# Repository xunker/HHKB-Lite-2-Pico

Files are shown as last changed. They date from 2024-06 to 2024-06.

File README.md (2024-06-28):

**IMPORTANT**: Current design (June 2024) is *NOT* completely functional. Please
see [TODO.md](TODO.md) for more info.

# Pi Pico SMD controller relacement for HHKB Lite 2

Based on the [Teensy 2.0 controller by
thirteen37](https://github.com/thirteen37/HHKB-Lite-2-Teensy).

This is a QMK-compatible replacement controller for the [HHKB Lite
2](https://deskthority.net/wiki/HHKB_Lite), identified by model numbers
PD-KB200W/U or PD-KB200B/U.

This Lite version of the HHKB is a membrane keyboard and not exactly popular
compared to more expensive Professional versions that use Topre switches. But
the wiring is simple and is a good first project for modding commercial
keyboards.

This replacement uses a [Raspberry Pi Pico or Pico
W](https://www.raspberrypi.com/products/raspberry-pi-pico/), which is cheap, has
plenty of pins, and is supported by works well with the [QMK
firmware](https://github.com/qmk/qmk_firmware/blob/master/docs/platformdev_rp2040.md).
Note, this board uses the Pico as an SMD component (for space considerations)
and needs a Pico that *does not* have headers pre-soldered.

If you don't mind losing the built-in USB ports, then only 4 parts are required:
this PCB, two FFC connectors, and a Pi Pico. Optionally, you can add the
necessary components to integrate a USB 2.0 hub and keep using the built in USB
ports -- with the added benefit that they are now USB 2.0!

## Steps

1. Acquire/fabricate the PCB.
2. Get the parts
3. Disassemble the keyboard.
4. Solder the components on to the board. Take care to leave enough room for the
   USB cable.
5. Reconnect the flex cables and insulate the backplate.
6. Get the USB cable you will be using and insert it through the keyboard
   connector hole and plug it in to the Pi Pico.
7. Flash your firmware and test your keyboard.
8. Reassemble the shell.

### PCB fabrication

The fabrication-ready files are in `plots/`. Just send them to your preferred
fab. It is a pretty standard 1.6mm PCB with conservative via and track
parameters that just about any shop can handle.

> TODO: Change this to pi pico
>
> You can also [order the PCBs through
PCBway](https://www.pcbway.com/project/shareproject/HHKB_Lite_2___Teensy_2_0_controller.html).
With their new user discount, you would only have to pay shipping.

### Parts

#### Minimum Parts

* 1 [Pi Pico or Pico W](https://www.raspberrypi.com/products/raspberry-pi-pico/)
  (WITHOUT headers)
* 1 Molex Easy-On 14-pin 1.25mm pitch FFC connector 39-53-2145
* 1 Molex Easy-On 8-pin 1.25mm pitch FFC connector 39-53-2085
* MicroUSB or USB-C cable for the Pi Pico, depending on which model (or clone)
  you have.

#### Optional Extras

To re-enable the built-in USB ports, add:
* FE1.1s IC, revision B or later, SSOP package
* 12mhz crystal, 16-20pf, 4-pin 3225 package
* (2x) 10uF capacitors, 1206 package
* 2.7K-10k resistor, 805 package
* A MicroUSB to USB-A cable you don't mind cutting apart

For USB Status LEDs add:
* (3x) 220-470 ohm resistors, 805 package
* (5x) LED (any colour), 805 package

### Bonus connectors

There are several extra breakouts you can use for your own fun:

* External reset/power connector (J1), needs:
   - 2.7K-10k resistor, 805 package
   - 2.54mm header, through-hole, 1x3 positions
* 3rd, hidden USB 2.0 port (J5, back of board)
   - Needs 2.54mm header, through-hole (but soldered as SMD), 4 positions
* Breakout of the remaining unused Pi Pico Pins (J6)
   - Needs 2.54mm header, through-hole, 2x4 positions
   - Provides access to GP22, GP25, GP27, GP28, VBUS, and 3V3

### Disassembly

The keyboard is held together by a few screws. Don't forget the screw hiding
under the label. When the shell is open, there are also further one screw
holding down the metal backplate and one screw each for the PCBa.

Screw locations

The USB cable can be removed from the shell but does not need to be detached
from the PCB. We will be using another USB cable instead.

The flex cables can be eased out gently. There is no latching mechanism.

### Modify the USB cable

> TODO: Change this to pi pico
>
>The Mini-USB plug that goes to the Teensy needs to be shaved down to save about
>1mm of thickness.

Shaved USB

### Soldering the board

> TODO: Change this to pi pico My recommended order is:
> 1. Headers for Teensy on to the board
> 2. Molex connectors
> 3. Teensy

The Molex connectors are oriented in opposite directions, with pin 1 (the edge
with a little notch) of each connector facing each other. This is important
because the flex cables and connectors are single sided.

> TODO: Change this to pi pico Note that the Teensy should be mounted upside
> down, on the same side as the connectors. This is to save a couple of
> millimeters of space from the stacked height of the connectors. You may have
> to trim down the header pins after you've soldered on the Teensy. The USB
> cable should still be able to fit.
>
> Teensy upside down
>
> Teensy clearance

### Connect flex cables and insulate the backplate

Connect the flex cables to the PCB. Note the orientation.

The metal backplate should be insulated, at least around the area of the PCB, to
minimize the risk of it shorting the board. I use a few strips of electrical
insulation tape here.

Insulated backplate

### Flash the firmware and test

> Plug in the USB cable to your computer and flash the firmware. There's a copy
> of the firmware with the default layout at `firmware/hhkblite2.hex`.
>
> Programming is done using [Teensy
> Loader](https://www.pjrc.com/teensy/loader.html). Since the Teensy is mounted
> upside down and the reset button no longer exposed, you can short the `RST`
> and `GND` pins instead.

After a successful initial flash, you can use the `reset` key to enter flashing
mode instead of having to open the keyboard. On my default configuration, the
`reset` key is `Fn` + `Esc`.

After flashing, you should be able to type something. It's easiest to just put
the silicone membrane over the traces and try typing something.

### Reassembly

The PCB here only uses one of the original PCB mounting screws. Route the USB
cable around the internal strain relief. Don't forget the screw for the
backplate.

You're done!

## PCB details

This is a [KiCad](https://kicad.org/) project, but you can find the generated
fabrication files in `plots/`. Just send them to your preferred PCB factory.

The schematics are fairly straightforward, with 8 row pins and 14 column pins:

> TODO: Change this to pi pico Schematic

The PCB layout is likewise simple:

> TODO: Change this to pi pico PCB

## Firmware

The configuration in `firmware/` can be uploaded to [Keyboard Firmware
Builder](https://kbfirmware.com/) to generate firmware for the standard US
QWERTY layout.

QWERTY keymap

There will be a warning "Not every key has a unique position in the wiring
matrix". This can be ignored and it is due to both `Fn` keys being wired exactly
the same. You should take note of this when designing your own layouts: it is
not possible to assign different keycodes to each `Fn` key as they are
electrically indistinguishable.

The wiring matrix is a bit of a mess, as is typical of membrane keyboards that
do not have diodes to prevent ghosting: the matrix is designed to minimize
ghosting from common key combinations but will never completely eliminate it.

> TODO: Change this picture to one for pi pico or remove Wiring > matrix
>
> The pin assignments are:
>
> | Matrix    | Pico Pin |
> |-----------|----------|
> | *Rows*    |          |
> | 0         | GP7      |
> | 1         | GP6      |
> | 2         | GP5      |
> | 3         | GP4      |
> | 4         | GP3      |
> | 5         | GP2      |
> | 6         | GP1      |
> | 7         | GP0      |
> | *Columns* |          |
> | 0         | GP8      |
> | 1         | GP9      |
> | 2         | GP10     |
> | 3         | GP11     |
> | 4         | GP12     |
> | 5         | GP12     |
> | 6         | GP14     |
> | 7         | GP15     |
> | 8         | GP21     |
> | 9         | GP20     |
> | 10        | GP19     |
> | 11        | GP18     |
> | 12        | GP17     |
> | 13        | GP16     |
>

## Quirks

It might seem like GP9 isn't working because there are no keypresses for that
pin. But that's by design, it's a dedicated pin for `Fn`. Took me two days of
debugging to notice that, so to help future people I've updated the QMK config
to light up the built-in LED when Fn is pressed, so you can see it does
something!

## Credit

[Original Teensy project by
thirteen37](https://github.com/thirteen37/HHKB-Lite-2-Teensy).

Pi Pico footprint is [konkers/KiCad-RP-Pico](https://github.com/konkers/).

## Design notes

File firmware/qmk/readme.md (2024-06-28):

# HHKB Lite 2 - Pi Pico

HHKB Lite 2

This is for the [HHKB Lite 2](https://deskthority.net/wiki/HHKB_Lite)
by PFU, identified by model numbers PD-KB200W/U or PD-KB200B/U, to have the
controller replaced by a Raspberry Pi Pico using
[this project](https://github.com/xunker/HHKB-Lite-2-Pico).

This firmware is based on the Teensy 2.0 controller replacement, which can be
found in the [hhkb_lite_2 directory](../hhkb_lite_2/).

Make example for this keyboard (after setting up your build environment):

    make hhkb_lite_2_pico:default

Flashing example for this keyboard:

    make hhkb_lite_2_pico:default:flash

See the [build environment setup](https://docs.qmk.fm/#/getting_started_build_tools) and the [make instructions](https://docs.qmk.fm/#/getting_started_make_guide) for more information. Brand new to QMK? Start with our [Complete Newbs Guide](https://docs.qmk.fm/#/newbs).

## Details

The `default` keymap is nearly the official standard US QWERTY, except
with the `Delete` key behaving like `BS`, which is as if DIP `SW3` is
set.

While there are two physical `Fn` keys on the keyboard, they are
electrically indistinguishable (same wiring matrix) so they can not be
assigned different keycodes.

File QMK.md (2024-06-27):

Building QMK for HHBK Pi Pico

WORK IN PROGRESS

https://github.com/qmk/qmk_firmware/blob/master/docs/cli.md

`brew install qmk/qmk/qmk`
`export QMK_HOME='~/qmk_firmware'` # Optional, set the location for qmk_firmware
`qmk setup`  # This will clone qmk/qmk_firmware and optionally set up your build environment

https://github.com/qmk/qmk_firmware/blob/master/docs/custom_matrix.md

`cd ~/qmk_firmware/keyboards/hhkb_lite_2_pico/keymaps/via`
`qmk compile`
`open ~/qmk_firmware/.build`

Drag .uf2 file to Pi Pico

To reset Pico in bootloader mode, hold `BOOTSEL` button while plugging in or
while shorting `run` pin to ground.

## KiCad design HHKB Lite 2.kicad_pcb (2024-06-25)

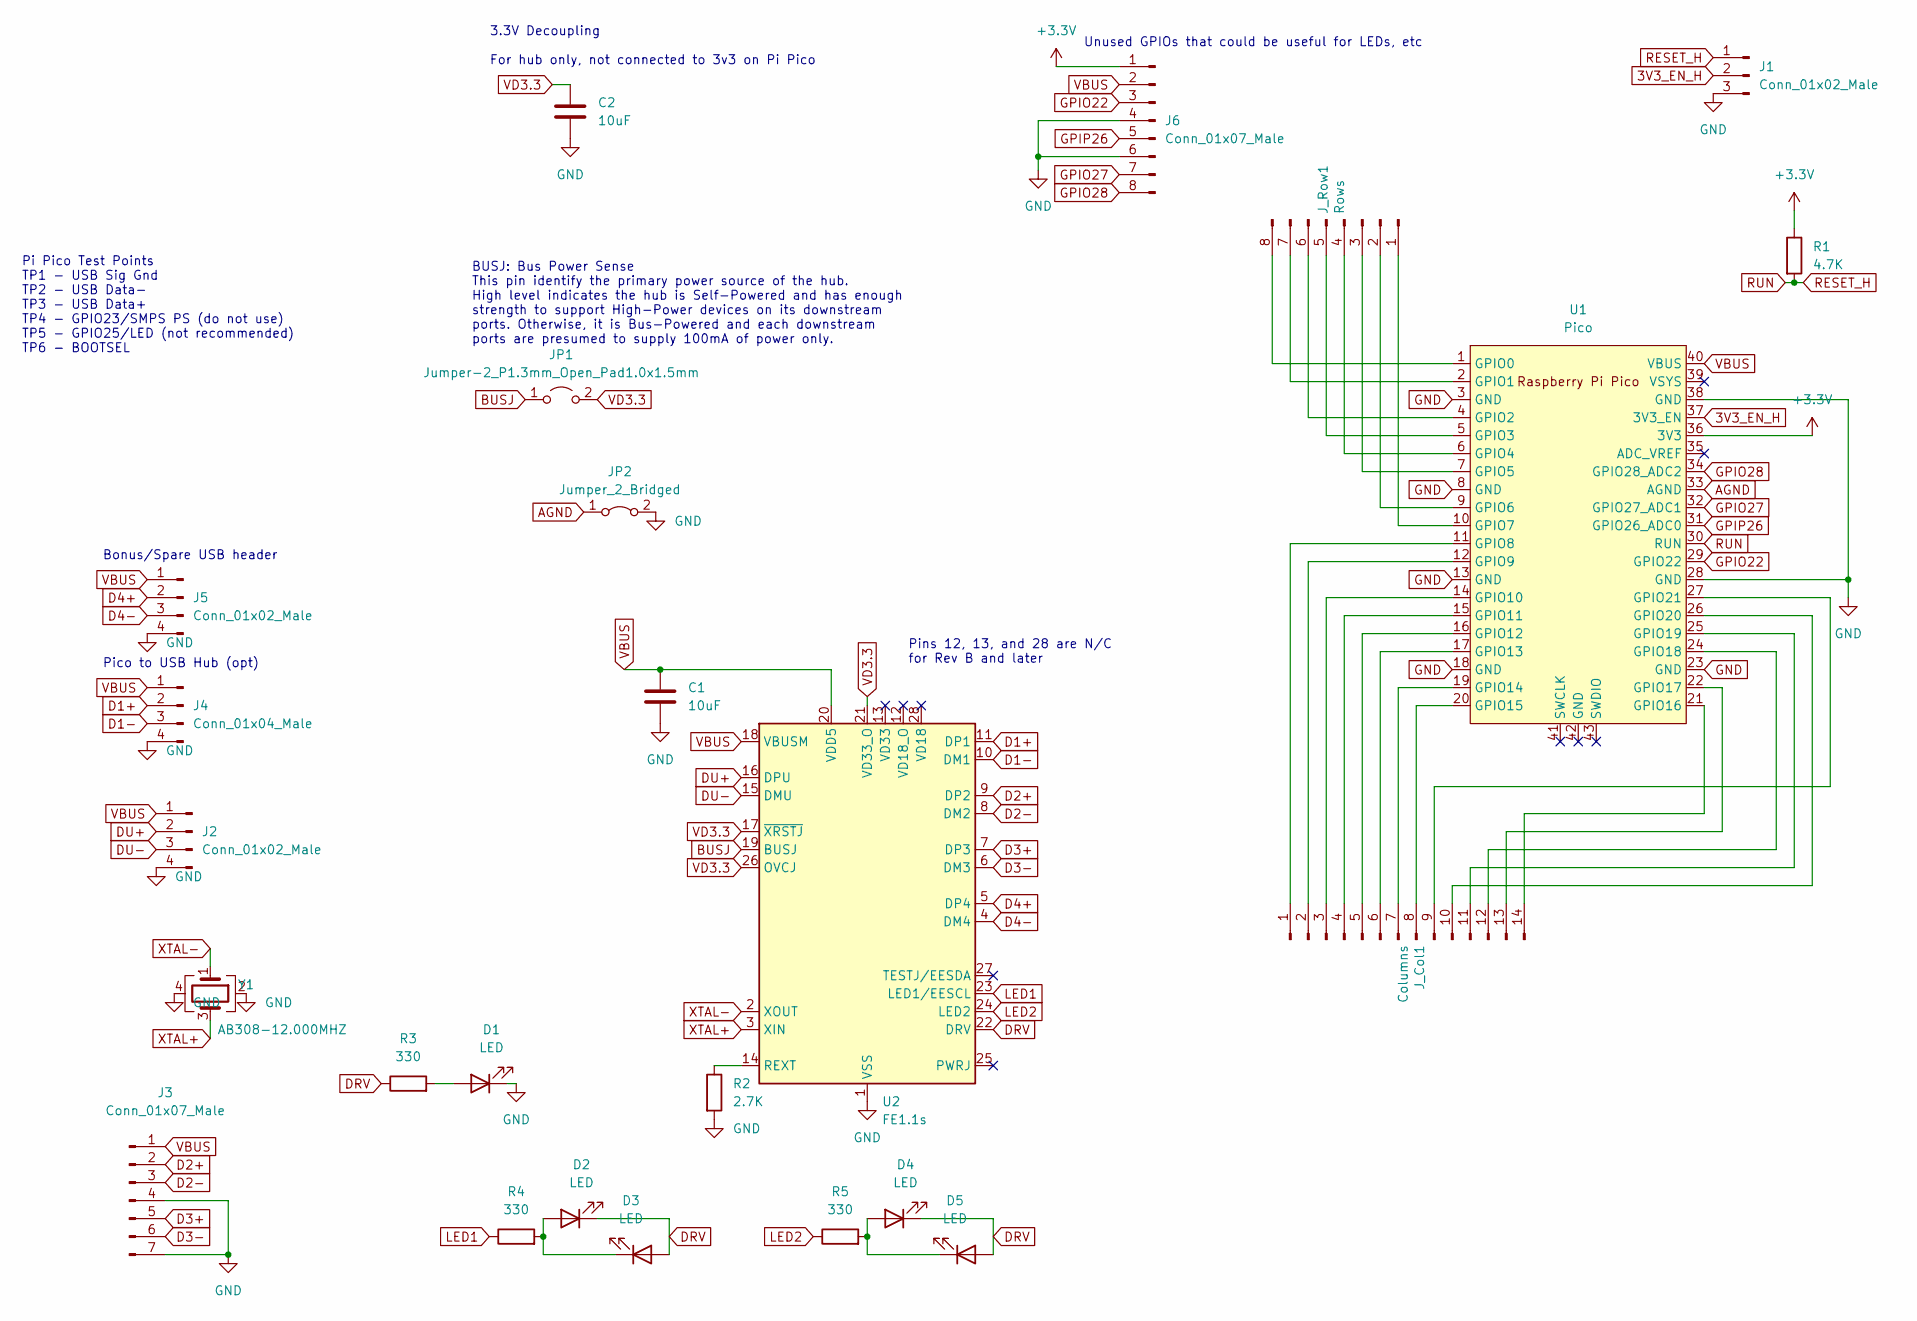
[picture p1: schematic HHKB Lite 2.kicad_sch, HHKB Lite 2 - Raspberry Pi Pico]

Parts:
C1, C2: 10uF; C_1206_3216Metric
D1, D2, D3, D4, D5: LED; LED_0805_2012Metric_Pad1.15x1.40mm_HandSolder
J1: Conn_01x02_Male; PinHeader_1x03_P2.54mm_Vertical
J2: Conn_01x02_Male; PinHeader_1x04_P2.54mm_Vertical
J3: Conn_01x07_Male; PinHeader_1x07_P2.54mm_Vertical
J4: Conn_01x04_Male; PinHeader_1x04_P2.54mm_Vertical
J5: Conn_01x02_Male; 2.54mm 1x4 header edge
J6: Conn_01x07_Male; PinHeader_2x04_P2.54mm_Vertical
JP1: Jumper-2_P1.3mm_Open_Pad1.0x1.5mm; SolderJumper-2_P1.3mm_Open_Pad1.0x1.5mm
JP2: Jumper_2_Bridged; SolderJumper-2_P1.3mm_Bridged_RoundedPad1.0x1.5mm
J_Col1: Columns; Molex_Easy-On_39-53-2144_14-Contacts
J_Row1: Rows; Molex_Easy-On_39-53-2084_8-Contacts
R1: 4.7K; R_0805_2012Metric_Pad1.20x1.40mm_HandSolder
R2: 2.7K; R_0805_2012Metric_Pad1.20x1.40mm_HandSolder
R3, R4, R5: 330; R_0805_2012Metric_Pad1.20x1.40mm_HandSolder
U1: Pico; RPi_Pico_SMD
U2: FE1.1s; SSOP-28_3.9x9.9mm_P0.635mm
Y1: Part AB308-12.000MHZ

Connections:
3V3_EN_H: J1.2, U1.37 (3V3_EN)
+3V3: J6.1, R1.1, U1.36 (3V3)
AGND: JP2.1 (A), U1.33 (AGND)
BUSJ: JP1.1 (A), U2.19 (BUSJ)
D1+: J4.2, U2.11 (DP1)
D1-: J4.3, U2.10 (DM1)
D2+: J3.2, U2.9 (DP2)
D2-: J3.3, U2.8 (DM2)
D3+: J3.5, U2.7 (DP3)
D3-: J3.6, U2.6 (DM3)
D4+: J5.2, U2.5 (DP4)
D4-: J5.3, U2.4 (DM4)
DRV: D2.1 (K), D3.2 (A), D4.1 (K), D5.2 (A), R3.1, U2.22 (DRV)
DU+: J2.2, U2.16 (DPU)
DU-: J2.3, U2.15 (DMU)
GND: C1.2, C2.2, D1.1 (K), J1.3, J2.4, J3.4, J3.7, J4.4, J5.4, J6.4, J6.6, JP2.2 (B), R2.2, U1.3 (GND), U1.8 (GND), U1.13 (GND), U1.18 (GND), U1.23 (GND), U1.28 (GND), U1.38 (GND), U2.1 (VSS), Y1.2, Y1.4
GPIO22: J6.3, U1.29 (GPIO22)
GPIO27: J6.7, U1.32 (GPIO27_ADC1)
GPIO28: J6.8, U1.34 (GPIO28_ADC2)
GPIP26: J6.5, U1.31 (GPIO26_ADC0)
LED1: R4.1, U2.23 (LED1/EESCL)
LED2: R5.1, U2.24 (LED2)
unnamed: D1.2 (A), R3.2
unnamed: D2.2 (A), D3.1 (K), R4.2
unnamed: D4.2 (A), D5.1 (K), R5.2
unnamed: J_Col1.1, U1.11 (GPIO8)
unnamed: J_Col1.2, U1.12 (GPIO9)
unnamed: J_Col1.3, U1.14 (GPIO10)
unnamed: J_Col1.4, U1.15 (GPIO11)
unnamed: J_Col1.5, U1.16 (GPIO12)
unnamed: J_Col1.6, U1.17 (GPIO13)
unnamed: J_Col1.7, U1.19 (GPIO14)
unnamed: J_Col1.8, U1.20 (GPIO15)
unnamed: J_Col1.9, U1.27 (GPIO21)
unnamed: J_Col1.10, U1.26 (GPIO20)
unnamed: J_Col1.11, U1.25 (GPIO19)
unnamed: J_Col1.12, U1.24 (GPIO18)
unnamed: J_Col1.13, U1.22 (GPIO17)
unnamed: J_Col1.14, U1.21 (GPIO16)
unnamed: J_Row1.1, U1.10 (GPIO7)
unnamed: J_Row1.2, U1.9 (GPIO6)
unnamed: J_Row1.3, U1.7 (GPIO5)
unnamed: J_Row1.4, U1.6 (GPIO4)
unnamed: J_Row1.5, U1.5 (GPIO3)
unnamed: J_Row1.6, U1.4 (GPIO2)
unnamed: J_Row1.7, U1.2 (GPIO1)
unnamed: J_Row1.8, U1.1 (GPIO0)
unnamed: R2.1, U2.14 (REXT)
RESET_H: J1.1, R1.2, U1.30 (RUN)
VBUS: C1.1, J2.1, J3.1, J4.1, J5.1, J6.2, U1.40 (VBUS), U2.18 (VBUSM), U2.20 (VDD5)
VD3.3: C2.1, JP1.2 (B), U2.17 (~XRSTJ), U2.21 (VD33_O), U2.26 (OVCJ)
XTAL+: U2.3 (XIN), Y1.3
XTAL-: U2.2 (XOUT), Y1.1

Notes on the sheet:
Unused GPIOs that could be useful for LEDs, etc
3.3V Decoupling For hub only, not connected to 3v3 on Pi Pico
Bonus/Spare USB header
Pico to USB Hub (opt)
Pi Pico Test Points TP1 - USB Sig Gnd TP2 - USB Data- TP3 - USB Data+ TP4 - GPIO23/SMPS PS (do not use) TP5 - GPIO25/LED (not recommended) TP6 - BOOTSEL
Pins 12, 13, and 28 are N/C for Rev B and later
BUSJ: Bus Power Sense This pin identify the primary power source of the hub. High level indicates the hub is Self-Powered and has enough strength to support High-Power devices on its downstream ports. Otherwise, it is Bus-Powered and each downstream ports are presumed to supply 100mA of power only.

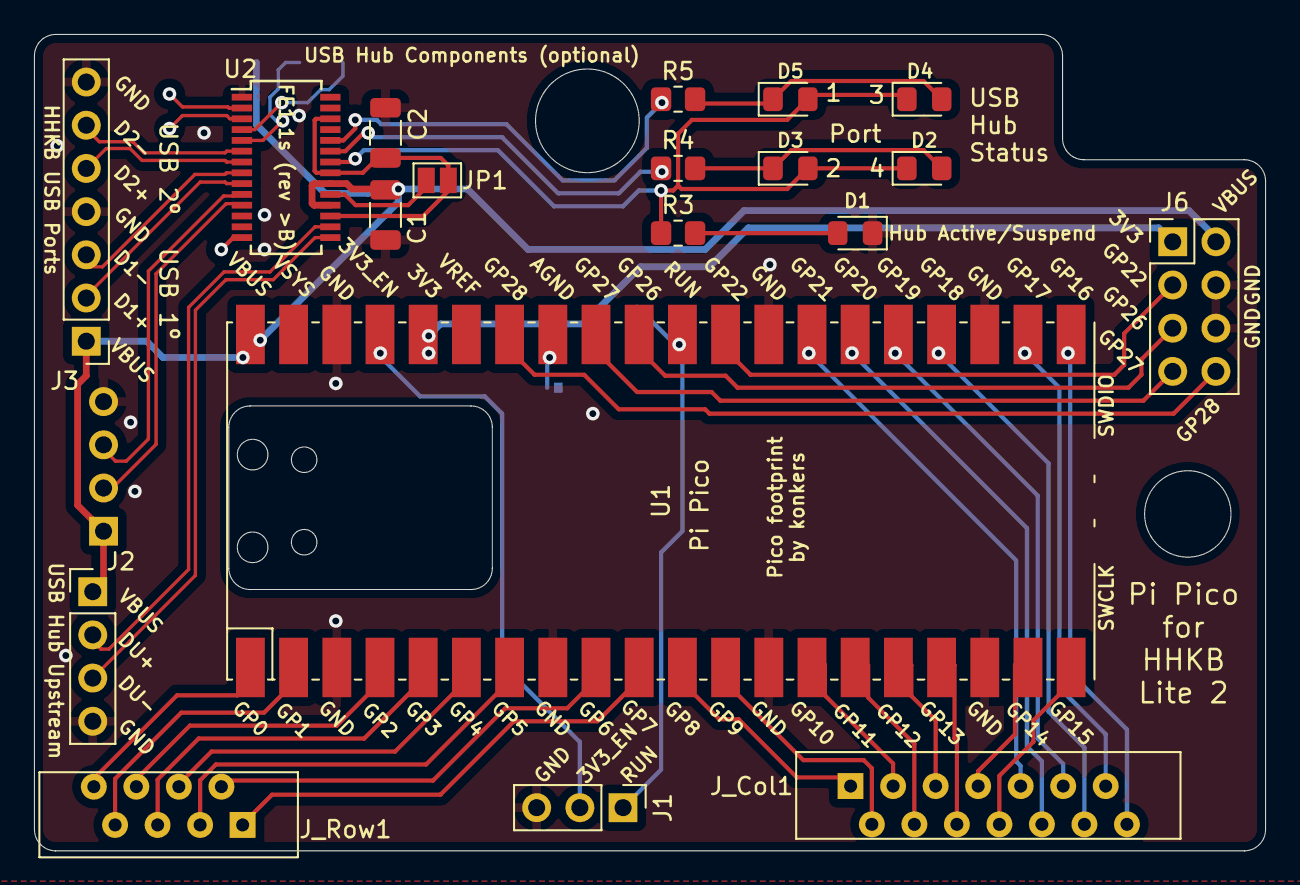
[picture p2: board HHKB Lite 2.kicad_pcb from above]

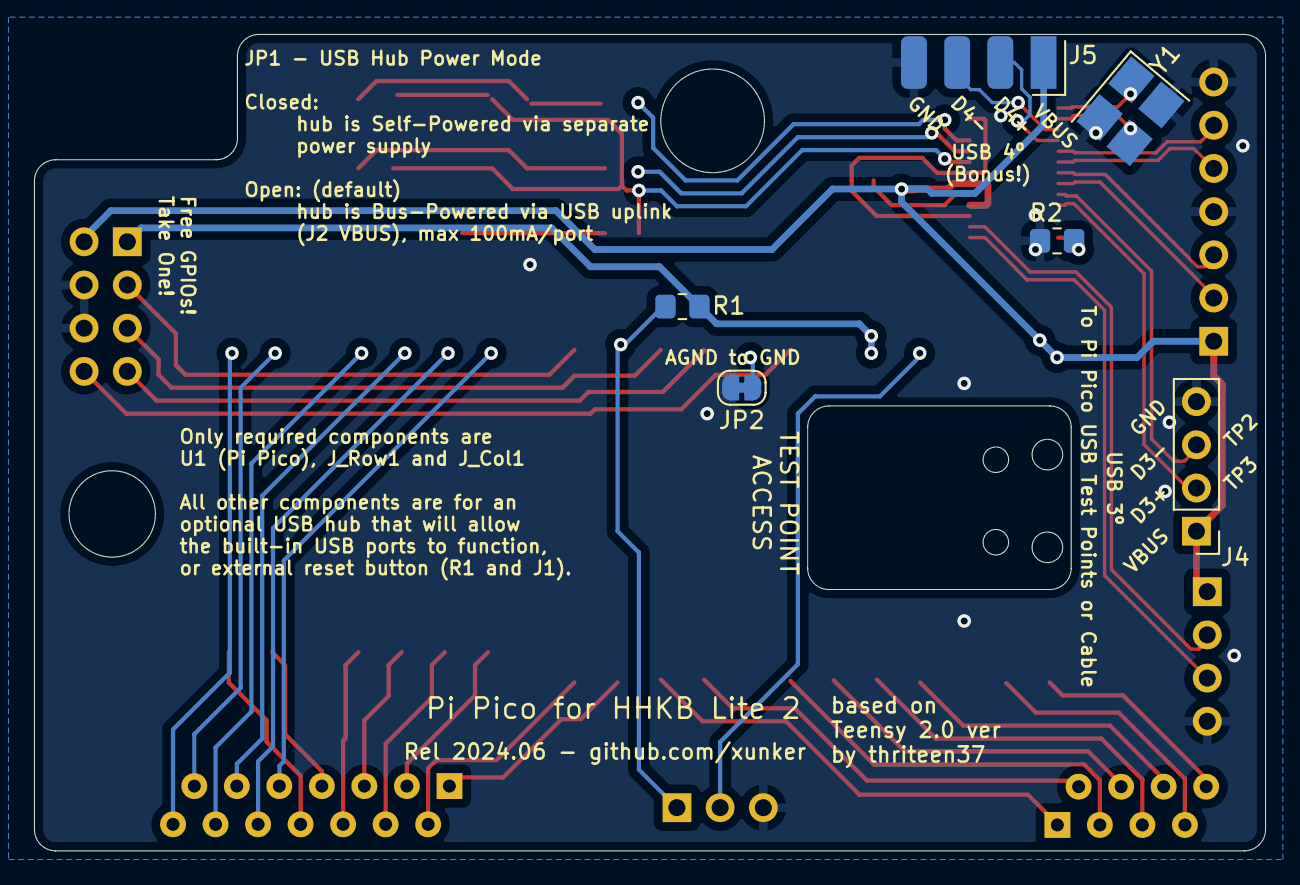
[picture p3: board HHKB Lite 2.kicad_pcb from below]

Board: 2 copper layers, 72.4 x 48.0 mm, 25 parts (6 on the bottom side), 53 nets.

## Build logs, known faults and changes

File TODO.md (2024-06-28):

# TODO List for HHKB Lite 2 Pico

Numbers indicate relative importance

## June 2024 Rev

### Move Right-Side Mount Hole 1️⃣

The mounting hole on the right side (nearest the Pi DEBUG connector) is too low
for my keyboard, making the board mount at an angle inside the case.

I don't know if this is an error in thirteen37's original design, or if their
keyboard has the hole in a slightly different place (since their stock
controller is also a little different from mine).

At first I thought it needed to be moved along the vertical/Y-axis, but when I
look at a printed overlay I think it needs to move toward the centre of the pcb.

I'm not sure, so another (probably more extensible idea) is to make that hole
quite a bit bigger, so it has a lot of adjustment play and can be cinched down
using a large nylon fender washer.

### Fix alignment and spacing of membrane connectors 1️⃣

On thirteen37's original design, J_Col1 (14-pin membrane connector) needs to be
moved about 2.5mm to the right (away from J_Row1). Or maybe they both need to
come to the centre by 1.25mm, not sure.

The miss-alignment is causing wrinkles in the membrane which in turn are causing
phantom key presses.

Like the mounting hole issue, I don't know if this is an issue with thirteen37's
design, or if they're keyboard uses a different membrane. I can't think of a
way to have adjustable spacing without resorting to multiple PCBs, so I'm going
to assume it was an honest mistake and try to make it conform to my keyboard.

### Change pinout of USB3 and USB Uplink to match original USB cable 2️⃣

Need to change the pinout of the 3rd USB connector (J4) and USB Uplink connector
(J2) to match the original USB KN connector. Simple swap of VBUS and GND is all
that is needed.

### xtal traces on FE1.1s do not need to be length-matched 2️⃣

The traces are not a true differential pair, they're simply in-out, so that
means they don't need to have the same length. That means I can mount the xtal
squarely instead of at an angle (and maybe on the top copper instead of bottom).

It also means I could use a different package than 3525, but I've already bought
a dozen in this package...

### Different Parts for the membrane connection? 2️⃣

This is a tough call.

The original Teensy design calls for the Molex Easy-On connector. This connector
specifies a sheet thickness of 0.3mm, but the membrane on my HHKB-Lite-2 is
0.42mm thick.

I can get the connector to make contact, but the retaining clip won't lock and
I've had to widen the slot on the retaining clip so that I can remove the
membrane (or else it gets stuck).

Clones of the original connectors (probably TE 84534-8) are available, but the
orientation of the pins is opposite so redesigning the board to use them would
make it so the Molex Easy-On can't be used.

### Add grounding-strap pad 3️⃣

Missing a pad to connect the grounding strap for the metal plate. This can be
connected to any GND spot on the PCB, but a specific pad would be nice.

### Move extra GPIO connection to bottom of board 3️⃣

Move the pins that are in JP6 to JP1, so all are accessible out the back of the
case. That way they could be used as jumper blocks, too, if needed.
It'll be a tight fit for the opening, so maybe using 2.0m headers instead of
2.54mm is in order?

It will need to be a 2x05 block, though only 9 pins are needed so could have
the remaining pin as an N/C or key pin? Have it line up with VBUS so if you use
a 2x05 connector and plug it in upside down, VBUS will remain disconnected and
not ruin anything.

#### Rework which pins are "bonus" 3️⃣

To avoid walking across the whole board, consider shifting the column pins to
the right by 4 so the "bonus" pins are GP8-GP11. That way they are a
straight-shot to the connector.

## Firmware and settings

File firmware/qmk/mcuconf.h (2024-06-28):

// Copyright 2024 Matthew Nielsen (@xunker)
// SPDX-License-Identifier: GPL-2.0-or-later

#pragma once

#include_next <mcuconf.h>

#undef RP_I2C_USE_I2C0
#undef RP_I2C_USE_I2C1
#define RP_I2C_USE_I2C0 FALSE
#define RP_I2C_USE_I2C1 FALSE

#undef RP_SPI_USE_SPI0
#undef RP_SPI_USE_SPI1
#define RP_SPI_USE_SPI0 FALSE
#define RP_SPI_USE_SPI1 FALSE

#undef RP_SIO_USE_UART0
#undef RP_SIO_USE_UART1
#define RP_SIO_USE_UART0 FALSE
#define RP_SIO_USE_UART1 FALSE

#undef RP_ADC_USE_ADC1
#define RP_ADC_USE_ADC1 FALSE

#undef RP_PWM_USE_PWM0
#undef RP_PWM_USE_PWM1
#undef RP_PWM_USE_PWM2
#undef RP_PWM_USE_PWM3
#undef RP_PWM_USE_PWM4
#undef RP_PWM_USE_PWM5
#undef RP_PWM_USE_PWM6
#undef RP_PWM_USE_PWM7
#define RP_PWM_USE_PWM0 FALSE
#define RP_PWM_USE_PWM1 FALSE
#define RP_PWM_USE_PWM2 FALSE
#define RP_PWM_USE_PWM3 FALSE
#define RP_PWM_USE_PWM4 FALSE
#define RP_PWM_USE_PWM5 FALSE
#define RP_PWM_USE_PWM6 FALSE
#define RP_PWM_USE_PWM7 FALSE

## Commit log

2024-06-25 Teensy 2.0 -> Pi Pico, sent to fab
    [HHKB Lite 2.kicad_pcb, HHKB Lite 2.kicad_sch]
2024-06-27 Updated after first test of fabbed boards
2024-06-28 WIP for QMK firmware, GP9 still not working
    [mcuconf.h]
2024-06-28 add note about xtal traces
2024-06-28 Figured out the GP9 problem!
    [mcuconf.h]
